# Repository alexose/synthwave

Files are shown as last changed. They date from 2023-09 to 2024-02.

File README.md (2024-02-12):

# Synthwave

An open-source experiment in carbon removal based on the electrochemical pH swing of seawater.


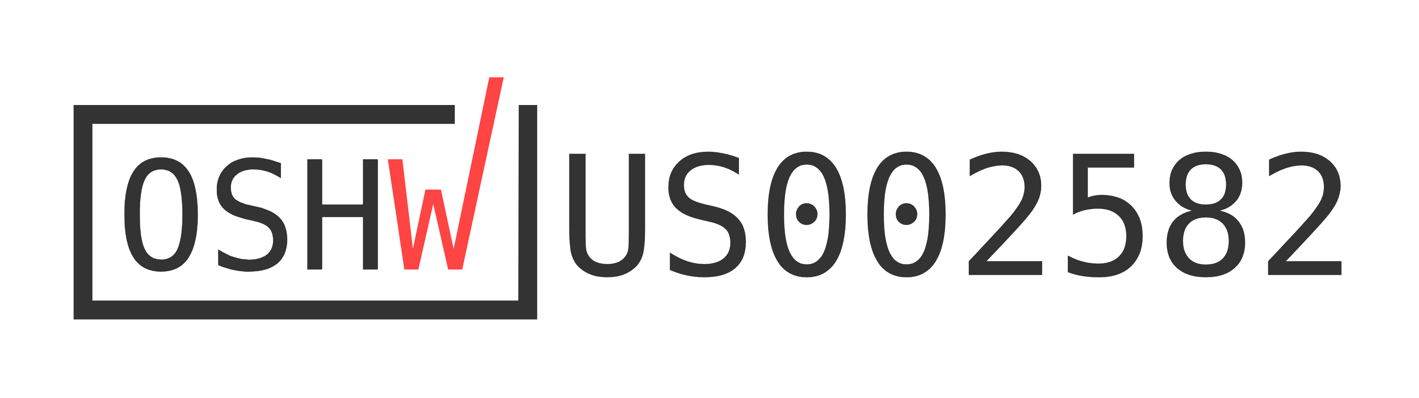
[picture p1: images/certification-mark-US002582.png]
OSHWA-Logo
[](https://certification.oshwa.org/us002582.html)

<p float="left">
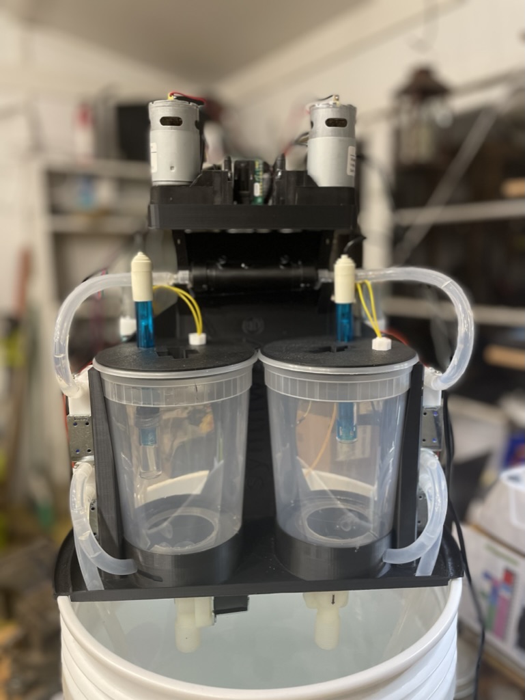
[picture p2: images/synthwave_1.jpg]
  
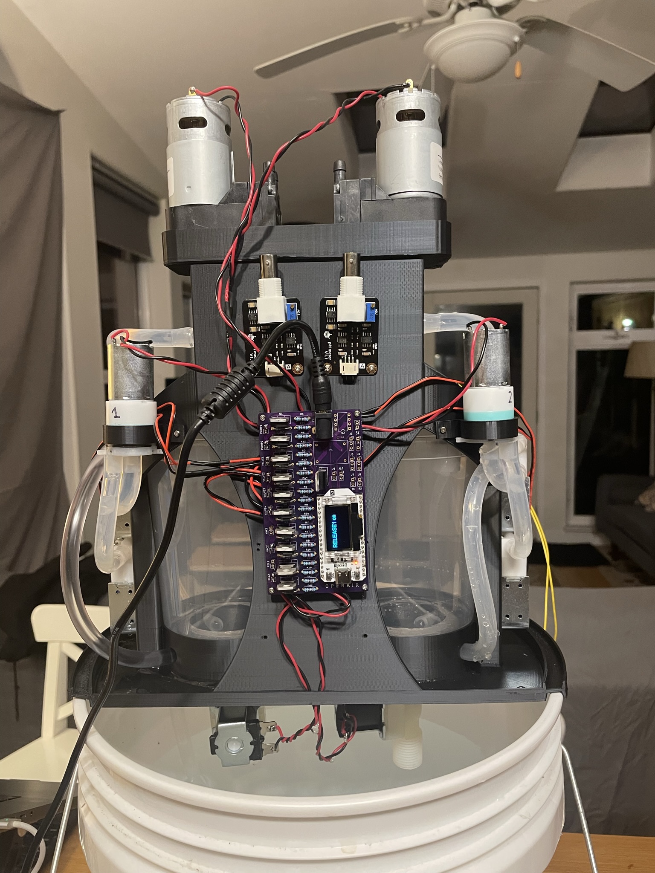
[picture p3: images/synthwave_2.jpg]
  
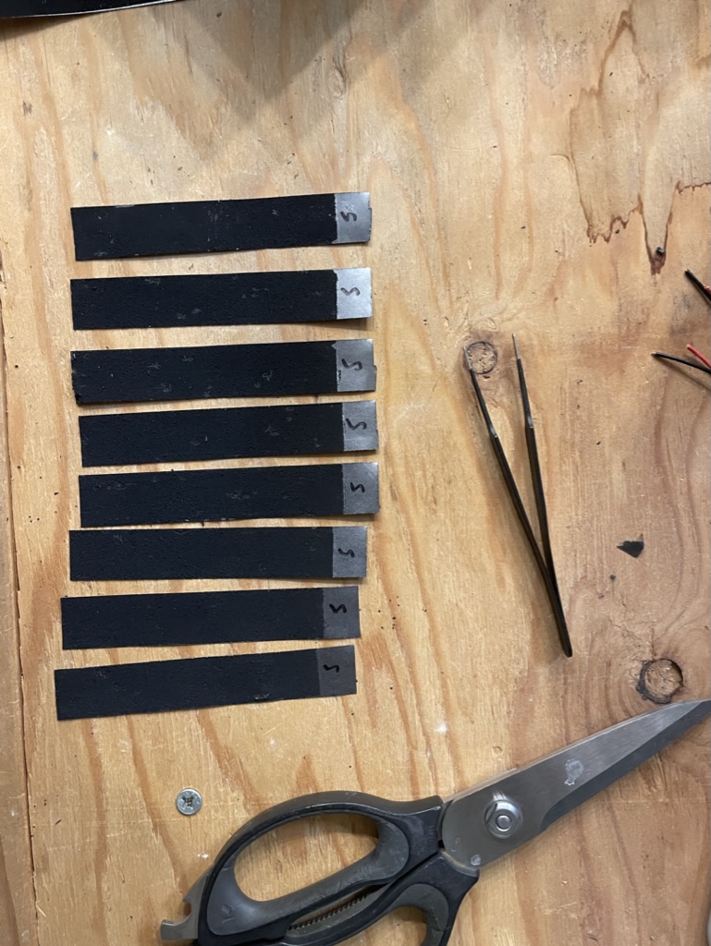
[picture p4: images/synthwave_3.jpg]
  
</p>

Developed by Alex Ose with input from many wonderful collaborators via the
[OpenAir Collective](https://openaircollective.cc/).

-   [OpenAir Forums](https://www.openairforum.org/t/introducing-synthwave/806)
-   [OpenAir Discord](https://openaircollective.cc/join)

## Introduction

Synthwave demonstrates the removal of CO2 from seawater using
[a technique developed by the Alan Hatton lab at MIT](https://pubs.rsc.org/en/content/articlelanding/2023/EE/d2ee03804h)
using a 3D printed shell and common, off-the-shelf components. With a materials list under $300, Synthwave is designed
to be an entry point for anyone looking to learn more about ocean-based carbon capture.

It is designed to be fully hackable, with an emphasis on approachability. Our goal is to bring ocean-based
electrochemical capture to a wider audience!

## Hardware

### Moving parts

The hardware is based around cheap 12V devices (that can easily be sourced from Amazon or eBay) controlled by a common
ESP32 microcontroller. The full list of materials can be found [here](MATERIALS.md).

### 3D printed parts

Each of the above parts are mounted onto a 3D printed frame that can be found in the `/model` directory of this repo.
Because it is designed to sit on top of a standard 5-gallon bucket, printing this frame requires a large-format printer
with a build area of at least 320x320mm.

There are several parts:

-   Base
-   Container cover
-   Back cover (optional)
-   Two pump brackets
-   Two strain relief brackets
-   Two electrode holders

Please refer to the README.md inside of the `/model` directory for pointers on how to print and assemble the device.

### Electrodes

As this is an electrochemistry project, it requires electrodes. While the exact formulation of these are under active
development, I would be happy to send you a working set of electrodes for free. Please get in touch with me directly in
order to arrange this.

Should you choose to develop your own electrodes, please consult
[this thread in the OpenAir forums](https://www.openairforum.org/t/synthwave-electrochemical-co2-capture-from-seawater/781/4)
for more information.

## Software

The software that controls this system is designed to be as readable as possible. It uses Arduino-compatible code to
connect to a local WiFi network and expose a simple API. This API accepts various parameters that allow a client to
toggle each individual pump, solenoid, and/or electrode set.

This allows us to control the system entirely from a web browser, which allows easy fine-tuning of process variables
without the need to continuously re-flash the ESP32 server.

Should you need to re-flash the ESP32, this can be accomplished via the /update endpoint. The software uses the
[ElegantOTA](https://github.com/ayushsharma82/ElegantOTA) library to allow for simple, over-the-air reflashing as to not
require a physical connection to the device.

## System modeling

Our current estimates show that Synthwave removes about of 0.076g of CO2 per run cycle[1]. Assuming a cycle time of five
minutes, an unlimited source of seawater, and non-degrading electrodes, it should be able to remove 22g of CO2 per day.

There are many, many variables that will affect this final number: The quality of the electrodes, the concentration of
CO2 in the seawater, the cycle frequency, and the efficiency of our electrochemical reaction.

Above all else, Synthwave aims to put our assumptions to the test, and help inform our next phase of research.

[1]: The original paper cites 0.0543 mmol of CO2 removed per cycle, with water volumes of about 30mL. Scaling this up to
1L gives us 1.7404 mmol, or 0.0766 grams of CO2.

## Future research

Synthwave is designed to be a simple demonstration of a specific carbon capture technique. In order to achieve
commercial viability, virtually all aspects of this technique will need to be improved.

The main need is to improve the quality of our electrodes. This will likely involve better coating techniques to avoid
degredation and fouling, as well as more accurate measurements, CV charts, etc.

With improved electrodes, the next step would be to improve the throughput of the device to handle much more seawater.
This could be achieved by increasing the size of the system, designing a more efficient cell (ideally a flow cell), or
perhaps building multiple machines to work in parallel with one another.

We hope that by publishing this work under the CERN license, future hackers and collaborators will share their
learnings. It is only by the overwhelming success of carbon capture do we hope to maintain a livable climate. By
investing your time and energy in projects like this one, we may uncover key techniques that make gigaton-scale carbon
capture viable.

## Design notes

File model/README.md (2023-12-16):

# Synthwave 3D Models

The following are a few notes on how to print this design. This is not meant to be a comprehensive tutorial. More of an
FAQ. Please consider checking out the [build log](https://www.openairforum.org/t/synthwave-build-log/904) for additional
guidance.

If you're having trouble with the build process, I encourage you to reach out to me directly in the OpenAir discord.

## Base

This is the main piece of Synthwave, and is responsible for consuming the majority of the filament. It's a big piece:
Around 320x320x235mm, and will require about half a roll of filament (500g) if printed at 10% infill.

If you don't have a big enough printer, you may use the base_no_lid.stl file. This model should print on a
standard-sized printer, but it requires you to purchase a lid for your five-gallon bucket and drill two holes in it.
These holes should line up with the flush valves. Done correctly, the flush valves will hold everything in place.

You'll notice several mounting points. These are designed for M2 screws. I highly recommend a set of assorted
self-tapping M2 screws for this project, as you may need many different lengths. Also, the holes are on the small side,
so you might want to drill them out ever so slightly to allow the screws to bite.

## Container cover

This sits on top of the two 32oz deli containers, and acts as a place to hold a pH probe, a float switch, and a pair of
electrodes.

## Pump brackets

These allow you to screw the two micro pumps to each side of the base.

## Electrode holders

These clips are designed to hold an electrode pair 1cm apart. They're meant to allow for quick electrode swaps, and are
supposed to sit just above the water line.

## Back cover (optional)

This piece is designed to protect the breadboard. It is not really needed unless you want to protect the electronics.

## Strain relief brackets (optional)

Instead of the back cover, you can also use these brackets to help secure all of the different wires in place.

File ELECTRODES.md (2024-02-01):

# Alex's Guide to DIY Carbon Paper Electrodes

## Introduction

Carbon paper electrodes are a good starting point for many electrochemical experiments. While there are many styles,
these ones lend themselves to DIY production.

In these examples, we will be creating two types of electrodes. One made with bismuth powder, and the other with silver
chloride powder. These happen to be the same types needed for [Synthwave](https://github.com/alexose/synthwave).

Note that I'm just a hobbyist, not a professional electrochemist. It is likely that there are better techniques than
this one-- However, this is the one I've found that works best for my particular setup and workflow.

## Materials Needed

I've provided links below, but they're likely to fall victim to [link rot](https://en.wikipedia.org/wiki/Link_rot) over
time. If a link isn't working, just do your best to find a suitable replacement.

I also included amounts, but keep in mind that this will buy you much more than you need for a single set of electrodes.
The intention here is that you'll have enough material to make as many as you want.

-   50g
    [Carbon Black](https://www.msesupplies.com/products/mse-pro-50g-super-p-conductive-carbon-black-for-lithium-ion-battery)
    (Carbon Powder)
-   50g
    [Polyvinylidene Floride](https://www.msesupplies.com/products/mse-pro-100g-polyvinylidene-fluoride-pvdf-binder-for-lithium-battery-research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),
    a binding agent
-   Metal powders, in this example both [bismuth](https://www.rotometals.com/bismuth-powder-99-99-325-mesh-1-pound/) and
    [silver chloride](https://www.ebay.com/itm/395123679024?hash=item5bff34df30:g:QNQAAOSwjy1fVxHt)
-   500mL of
    [NMP](https://www.laballey.com/products/nmp-1-methyl-2-pyrrolidone-lab-grade?utm_source=Klaviyo&utm_medium=flow)
    solvent
-   At least a square foot of .005" thickness
    [Carbon Paper](https://www.amazon.com/MinGraph-Flexible-Graphite-Thickness-Homogeneous/dp/B07K8Y4269) (AKA Graphite
    Paper)
-   A razor scraper. I like [this one](https://www.thingiverse.com/thing:2029655), personally, but anything will work
-   Ink casting guides (see below)
-   A digital scale that works in the thousandth range
-   A plastic spoon
-   Latex gloves

## Ink casting guides

The key to electrode creation is achieving a very thin and very even spread of "ink" onto a the sheet of carbon paper.
The high-end way to do this is with a CNC-assisted spray nozzle. The low-end way is to do something called the "doctor
blade" method, which involves laying down several layers of scotch tape in lines to a desired thickness, then using a
razor blade to smoothly cast the ink between the lines.

I use a modified doctor blade method, where I 3D print stencils rather than using up a whole roll of tape. The
electrodes I'm aiming for are 20 cm² rectangles, cast a depth of 200 μm (0.2mm). The files I use are
[included in the Synthwave repo](https://github.com/alexose/synthwave/blob/main/model/ink_spreader.stl), but are easy to
create on your own using the CAD tool of your choice.

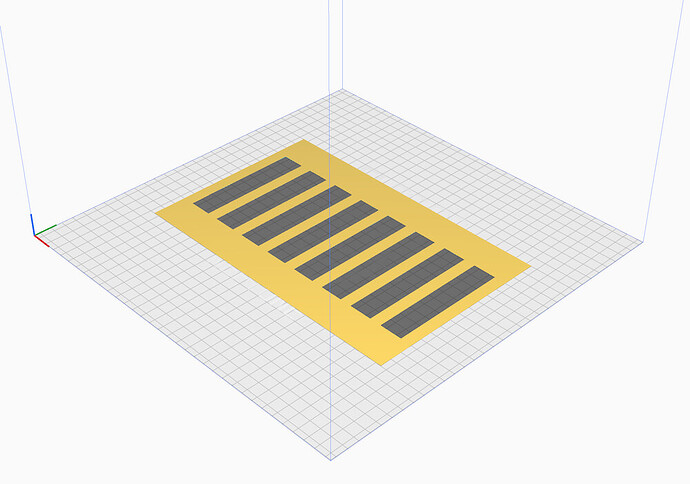
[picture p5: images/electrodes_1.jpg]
image|690x485, 50%


3d printers are excellent when it comes to making accurately-sized things. Do keep in mind that the first layer of any
3d print is mildly "squished", and may not end up _exactly_ the thickness you anticipate. Always good to verify with
calipers.

If you don't have a 3d printer, you may use the scotch tape method.

## Safety Precautions

While these ingredients aren't particularly toxic, please make sure to take proper safety precautions when handling
powders, solvents, and/or razor blades.

Carbon black is especially powdery, and is not very good for your when inhaled. Wear a mask!

This process can also be a little messy, so I like to wear latex gloves.

## Creating The Ink

Begin by weighing your ingredients. The [paper](https://pubs.rsc.org/en/content/articlelanding/2023/ee/d2ee03804h) that
I'm working from only states ratios, which is not particularly useful for knowing how much to make. For your
convenience, I've included exact weights for each ingredient, which will make enough ink to cover about 200 cm² of
surface area (so, 8 electrodes with a little bit of excess).

Tare your mortar and pestle on your scale, then carefully add:

-   0.4g carbon black
-   0.4g PVDF
-   3.2g bismuth powder (or silver chloride, depending on which you're making)
-   10.0g NMP solvent

Use your mortar and pestle to mix thoroughly. You're aiming for a perfectly smooth ink with no lumps.

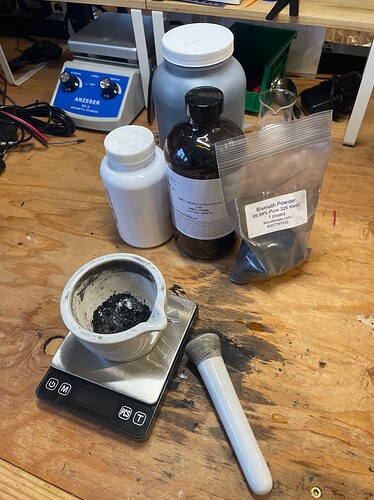
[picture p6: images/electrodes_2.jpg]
image|375x500, 50%
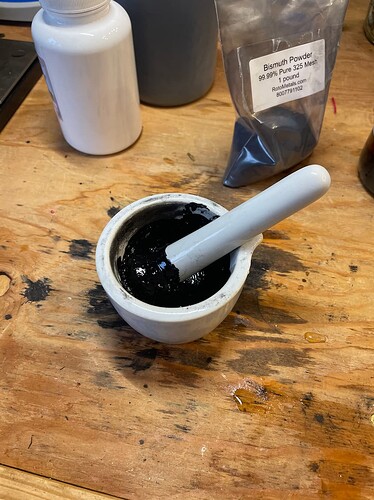
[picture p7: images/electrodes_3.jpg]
image|375x500, 50%
 

When you've achieved this, set up your casting station. My approach here is to tape the 3D printed stencil to both the
carbon paper and the workbench, then drop a spoonful of ink into each lane.

Now use your razor scraper to spread the ink as evenly as you can. Apply even pressure as you drag the razor scraper
across the stencil. You'll notice that the guide is designed to give you enough room to scrape two lanes at once. You
may then remove the stencil and admire your handywork.

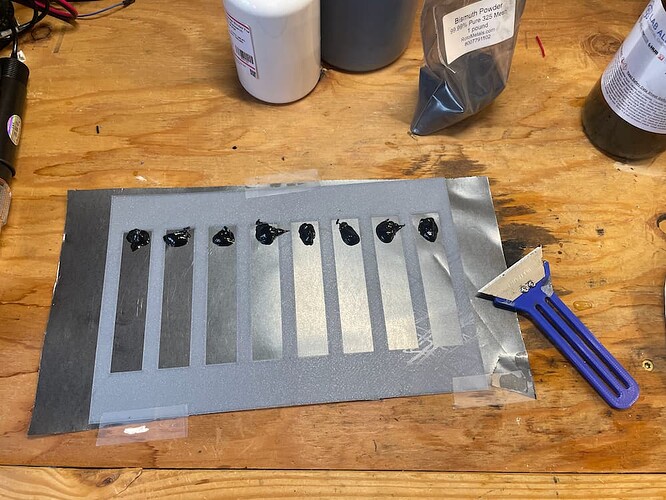
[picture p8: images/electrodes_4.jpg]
image|666x500, 50%
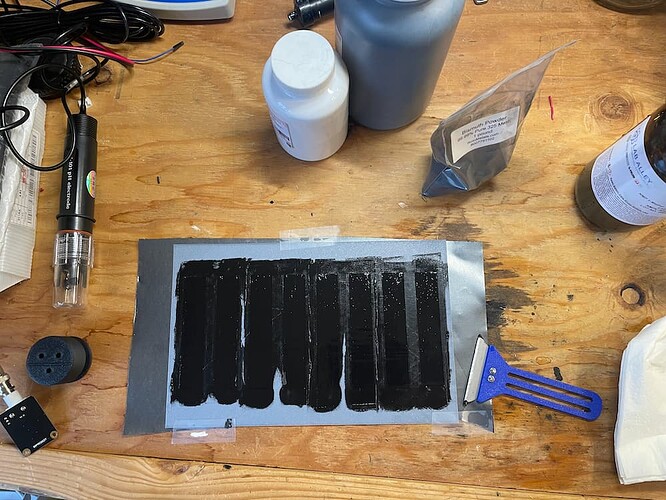
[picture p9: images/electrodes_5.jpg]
image|666x500, 50%
 
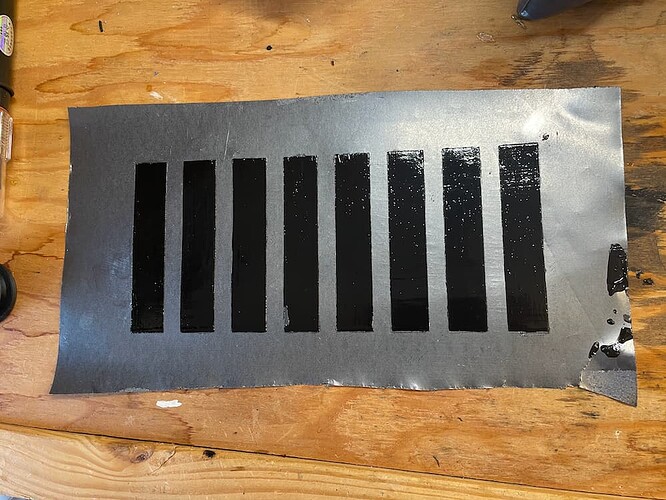
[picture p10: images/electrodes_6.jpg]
image|666x500, 50%


## Cleanup

The bad news is that this ink material is not water-soluable. The good news is that it tends to gel together and come
off in long sheets. The best way I've found to clean my implements is to splash them with very cold water, dry with a
paper towel, and repeat.

## Drying the electrodes

If you're in a hurry, you can dry them in an 180F oven for 3 hours (I personally use the back of a cookie sheet).
Otherwise, you can leave them at room temperature for 24 hours.

Once they're dry, carefully cut them into their desired shapes using scissors or a paper cutter.

Congratulations! You have now completed your first set of electrodes.

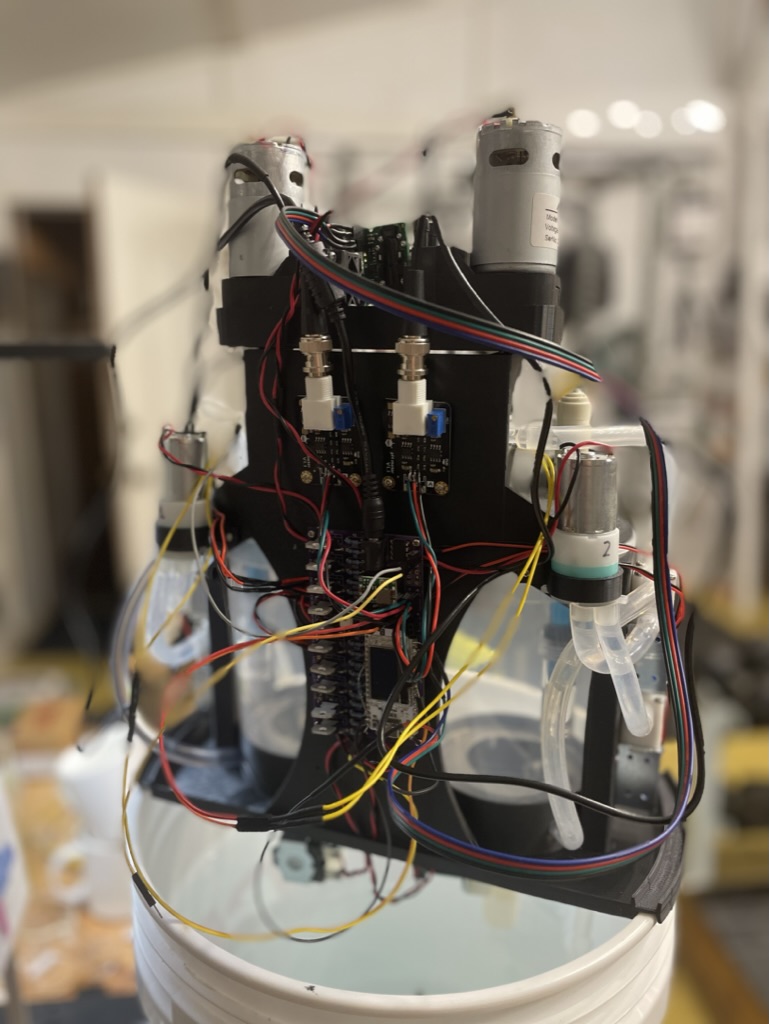
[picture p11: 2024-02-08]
images/synthwave_4.jpg

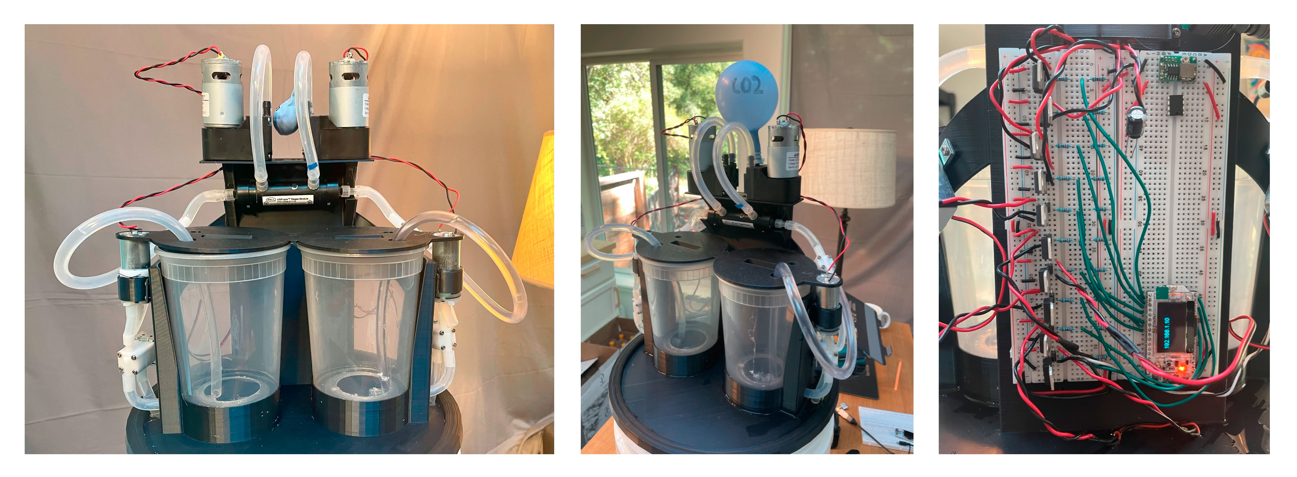
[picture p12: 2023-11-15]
images/synthwave.jpg

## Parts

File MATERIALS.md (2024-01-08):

# List of Materials

This should be everything you need to build a Synthwave. Note that these parts (and associated links) may change over
time. If in doubt, make sure to cross-reference with photos of existing builds.

## Custom Parts

Synthwave requires a few parts that can't be easily ordered off the internet. First is a 3d printed [shell](/model), as
well as several other 3d printed bits. I recommend using a good quality, large format 3d printer if possible. If you
only have access to a small printer, you may need to get creative.

You'll also need the official [Synthwave PCB](/pcb). This custom-designed board allows a simple ESP32 to control ten
different 12 volt devices at once, as well as breaking out various inputs and outputs needed for managing the
electrochemical process.

If you've never ordered a custom PCB, I highly recommend [OSHPark](https://oshpark.com/). You can order three boards for
about $40 (having extra is never a bad idea).

The board is designed to be populated by hand: Everything is through-hole, and nothing is surface mounted. If you're
experienced with soldering, this should take you about an hour or so. If you're not experienced with soldering, well,
this is a good opportunity to learn!

## Pumps

-   2 [DC 12V Water Flow Self Priming Diaphragm Micro Water Pumps](https://www.amazon.com/gp/product/B09NQZHBQ2) $25.18
    ($12.59 ea)
-   2
    [DC 12V Mini Vacuum Pump](https://www.amazon.com/gp/product/B071GL3XXQ/ref=ppx_yo_dt_b_search_asin_title?ie=UTF8&psc=1)
    $51.98 ($25.99 ea)

## Solenoids

-   2 [1/2 inch NPT Thread 12V DC GRAVITY-FEED Plastic Nylon Solenoid Valve](https://www.ebay.com/itm/290763981675)
    $31.98 ($15.99 ea). It is very important that you use GRAVITY FEED valves. Don't sub these out for "regular" valves,
    which require a certain amount of pressure to open.
-   4 [12V Two-Position Three-Way Electric Solenoid Valve](https://www.aliexpress.us/item/3256804915255792.html) $20
    (about $5 each) (Note there are a wide variety of these three-way solenoids. I highly recommend the ones with the
    barbed fittings.)

## Membrane Contactor

-   1 [UDM-21110 Ultifuzor Degas Module](https://www.ebay.com/itm/115469063200) ~$180 (I bought used for $75)
-   4 [Luer lock to 1/4 barb fitting adapter](https://www.amazon.com/gp/product/B0BB649WM2/) $7.99 (10 pack)

## Sensors + Electronics

-   1 [SCD30 CO2 sensor](https://www.amazon.com/extralife-Quality-Sensors-Module-Measurements/dp/B0BBGSQTYJ) $30.40
-   2 [Gravity Arduino-compatible pH sensors](https://www.dfrobot.com/product-1782.html) $79.00 ($39.50 ea)
-   1
    [Heltec Wifi Kit 32 V3 Development Board with OLED](https://www.amazon.com/HiLetgo-Display-Bluetooth-Internet-Development/dp/B07DKD79Y9)
    $17.39
-   1 [15V DC 3A Power Supply](https://www.amazon.com/Adapter-Switching-Converter-100V-240V-Positive/dp/B08CZD4HWG)
    $12.99
-   1 [Adafruit 4489 L9110H H-Bridge](https://www.amazon.com/gp/product/B085KYNY3H/) $5.18
-   1 [L7805CV Voltage Regulator](https://www.amazon.com/dp/B0C5M51R2Z) $5.99 (12 pack) 1
    [3 pin DC Power Connector, DC005 5.5x2.1mm](https://www.amazon.com/dp/B081DYQSC9) $5.99 (20 pack)
-   10 [TIP120 NPN 5A 60V Transistors](https://www.amazon.com/gp/product/B08BFYYK7D/ref=ppx_yo_dt_b_search_asin_title)
    $8.99 (20 pack)
-   2
    [LM2596S Adjustable Buck Converter](https://www.amazon.com/DiGiYes-Converter-Efficiency-Regulator-Adjustable/dp/B0BPSFVDY4)
    $8.69 (5 pack)

## PCB

## Electrode Materials

## Misc.

-   20 [2.2kohm 1/4 watt resistors](https://www.amazon.com/dp/B08QRPRVMJ) (used as hardware pulldowns) $5.49 (100 pack)
-   10 [30v 1A diodes](https://www.amazon.com/ALLECIN-1N5818-Schottky-Rectifier-Switching/dp/B0CKSHS9CM) (used as
    flyback diodes) $6.49 (150 pack)
-   10 feet [1/4" ID 3/8" OD silicone tubing](https://www.amazon.com/dp/B07W918CBP) ~ $5
-   Solid core wire for electronics
-   Shrink tubing
-   Wire strippers, needlenose pliers, soldering iron, etc.

You should expect everything to cost around **$400** total. Of course, it is quite a bit cheaper to source all the parts
from China if you don't mind the wait.

The most expensive individual part is the membrane contactor. It would be interesting to come up with an alternative for
this part, but I'm not sure what this would be. The pH sensors are optional, but very useful to monitor system
performance.

With careful attention to price, it would be possible to build this device for around $200.

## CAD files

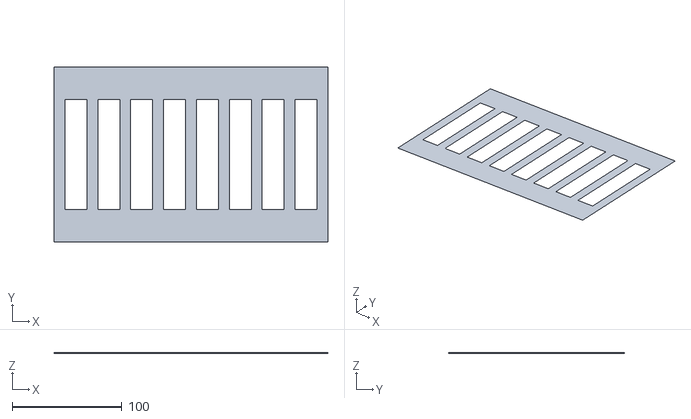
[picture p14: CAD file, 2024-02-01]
model/ink_spreader.stl
250.0 x 160.0 x 0.24

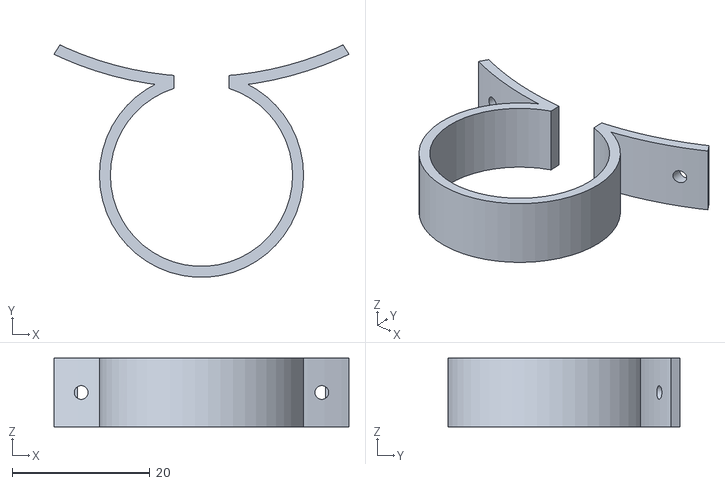
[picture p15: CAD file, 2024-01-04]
model/pump_bracket.stl
42.9 x 33.8 x 10.0

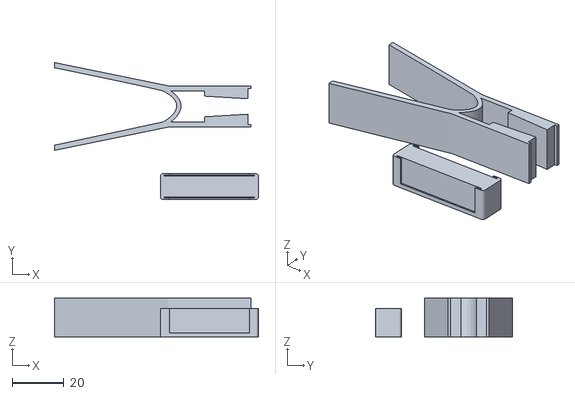
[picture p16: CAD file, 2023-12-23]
model/electrode_holder.stl
79.0 x 53.0 x 15.0

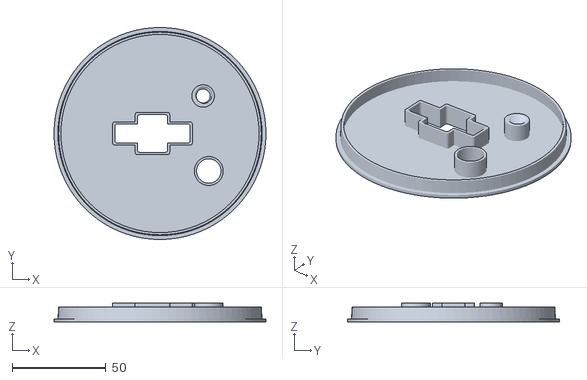
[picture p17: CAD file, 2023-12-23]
model/container_cover.stl
113.0 x 113.0 x 10.0

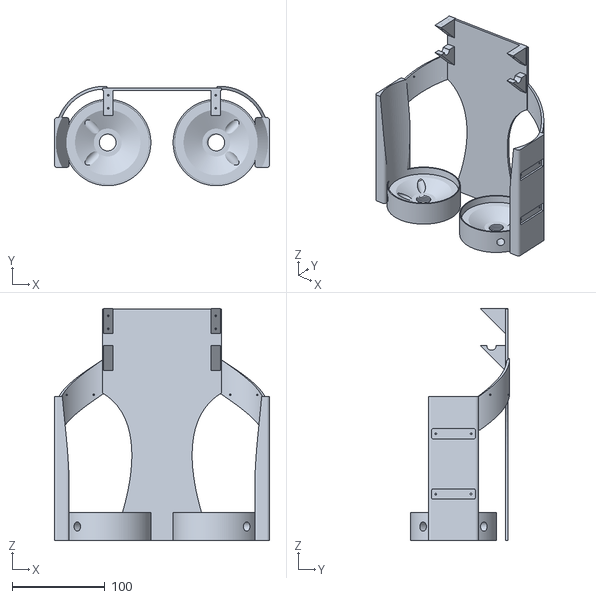
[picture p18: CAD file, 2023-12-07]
model/base_no_lid.stl
232.0 x 107.1 x 250.0

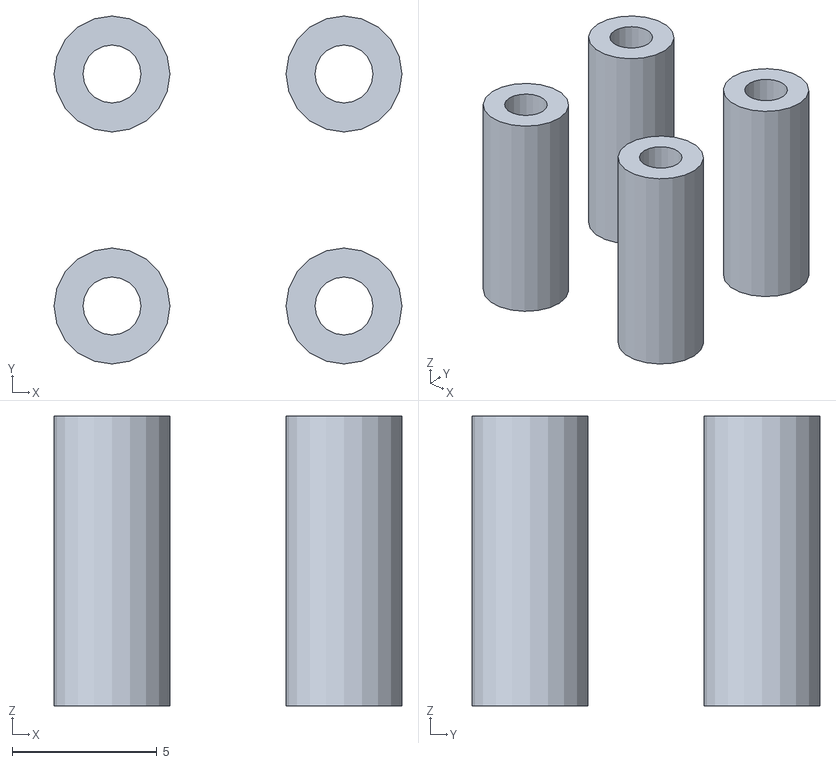
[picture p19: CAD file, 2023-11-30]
model/standoffs.stl
12.0 x 12.0 x 10.0

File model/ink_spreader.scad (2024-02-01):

// Modified Doctor Blade sheet
w = 250;
h = 160;
d = 0.24; // 240um

electrode_width = 20;
electrode_height = 100;

difference() {
    cube([w, h, d], true);
    
    // Loop to create multiple instances of the second cube
    for (x = [0 : 20+10 : 250]) {
        translate([x - w/2 + 20, 0, 0])
            cube([electrode_width, electrode_height, d+0.1], true);
    }
}

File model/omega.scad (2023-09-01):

h = 15; // height
w = 45; // flange width
fd = 6; // flange depth
d = 1.6; // thickness
r1 = 27 / 2; // outer radius
r2 = 1.8; // screw hole head radius
r3 = 0.8; // screw hole radius
d2 = 4; // screw hole head depth
o = 3.5; // screw hole offset (from outer edges)

b = 2; //vertical bump

$fn = 60;


translate([0, 0, h/2]) rotate([0, 90, 0]) difference() {
    union() {
        hull() standoffs(1, d, h, w);
        translate([0, 0, b]) rotate([90, 0, 90]) cylinder(h, r1+d, r1+d, center=true);
    }
    union() {
        translate([0, 0, b]) rotate([90, 0, 90]) cylinder(h, r1, r1, center=true);  
        translate([0, 0, -h]) cube([h, r1*2, h*2 + h/2], center=true);
        translate([0, w/2 - o, -d2]) cylinder(d + d2, r2, r2);
        translate([0, -w/2 + o, -d2]) cylinder(d + d2, r2, r2);
        translate([0, w/2 - o, -fd]) cylinder(fd + d, r3, r3);
        translate([0, -w/2 + o, -fd]) cylinder(fd + d, r3, r3);
    }
}


module standoffs(r, depth, height, width) {
    $fn = 20;
    d = depth + fd;
    x = height / 2 - r;
    y = width / 2 - r;
    
    translate([0,0,-fd]) union() { 
        translate([x, y]) cylinder(d, r, r);
        translate([x, -y]) cylinder(d, r, r);
        translate([-x, y]) cylinder(d, r, r);
        translate([-x, -y]) cylinder(d, r, r);
    }
}

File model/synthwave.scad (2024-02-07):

use <threads.scad>

base_radius = 283 / 2; // inner diameter of 5 gallon bucket in mm

container_bottom_radius = 89 / 2;
container_top_radius = 112 / 2;
container_height = 135.3;

pump_mount_depth = 8;
pump_mount_height = container_height + 20;

rear_wall_height = 245;
rear_wall_width = 128;
rear_wall_thickness = 3;

electrode_holder_width = 20;
electrode_holder_height = 12;
electrode_holder_depth = 5;
electrode_holder_radius = 1;

distance_between_containers = 14;

default_screw_radius = 1;

$fn = 50;

render_base = 1;
render_base_no_lid = 0;
render_electrode_holder = 0;
render_pump_bracket = 0;
render_container_cover = 0;
render_back_cover = 0;
render_standoffs = 0;

if (render_base) base();
if (render_base_no_lid) base(false);
if (render_electrode_holder) {
    translate([0, -20]) electrode_holder(); 
    clip();
}
if (render_pump_bracket) pump_bracket();
if (render_container_cover) container_cover();
if (render_back_cover) back_cover();
if (render_standoffs) pcb_standoffs();

module base(include_lid=true) {
    border_width = 10;
    dr = container_bottom_radius;
    bw = border_width;
    
    d = dr + bw * 2;
    r = 20;
        
    dist = dr + distance_between_containers;
    
    pw = 108;
    rw = 56;
    
    y = -3; // nudge forward
    
    // translate([dist, 0]) container();
    // translate([-dist, 0]) container();
    
    difference() {
        union() {
            if (include_lid) {
                lid();
            }
            translate([dist, y]) cylinder(30, r=dr+2, $fn = 140);
            translate([-dist, y]) cylinder(30, r=dr+2, $fn = 140);
            translate([pw, y]) mirror([0, 1, 0]) rotate([0, 0, 180]) pump_mount();
            translate([-pw, y]) pump_mount();
            translate([0, rw]) rear_wall();
            translate([pw + 4, 54.5, 107]) band(35);
            translate([-pw - 4, 54.5, 107]) mirror([1,0,0]) band(35);
        }
        
        a = 45;
        translate([dist, y, -5]) mirror([1, 0]) rotate([180, 180])  solenoid_funnel();
        translate([-dist, y, -5]) rotate([180, 180]) solenoid_funnel();
        translate([0, rw-2, 105]) rotate([90, 270, 0]) linear_extrude(1.2) text("synthwave", size=20, halign="center", valign="center", spacing=1.3);
    }

    module rear_wall() {
        h = rear_wall_height;
        o = rear_wall_thickness;
        w = rear_wall_width / 2;
        
        r = 1;
        w2 = 120;
        h2 = 60;
        
        difference() {
            rotate([90, 0]) rear_wall_polygon();
            translate([0, -1, 115]) rotate([-90, 0]) pcb_screw_holes();
            translate([-17, -1, 175]) rotate([-90, 0]) ph_meter_screw_holes();
            translate([0, -1, 55]) rotate([-90, 0]) ph_meter_screw_holes();
            translate([17, -1, 175]) rotate([-90, 0]) ph_meter_screw_holes();  
        }
        
        translate([0, 0, 175]) shelf();
        
        module rear_wall_cutouts() {
            r = 120;
            c = 35;
            h = 30;
            b = 80;
            $fn = 100;
            
            translate([r + c, 10, b]) rotate([90, 0]) cylinder(h, r=r);
            translate([-r - c, 10, b]) rotate([90, 0]) cylinder(h, r=r);
        }
        
        module rear_wall_holes() {
            r = 12/2;
            c = 48.3/2;
            h = 30;
            b = 205;
            $fn = 80;
            
            translate([r + c, 10, b]) rotate([90, 0]) cylinder(h, r=r);
            translate([-r - c, 10, b]) rotate([90, 0]) cylinder(h, r=r);
        }
    }
}

        
module rear_wall_polygon(height=1, offset=0, def=1) {
    h = rear_wall_height;
    w = rear_wall_width;
    t = rear_wall_thickness;
    
    hf = h / 32;
    wf = w / 24;
    
    // 24x32
    scale([1, 1, t]) 
    translate([-w/2, 0])
    linear_extrude(height)
    offset(r=offset)
    scale([wf, hf])
    if (def == 1){
        rear_wall_polygon_def();
    } else {
        rear_wall_polygon_def2();
    }
}

module rear_wall_polygon_def() {
    polygon([[2,0/*1:0,0,0,0*/] ,[3.07,0] ,[4.08,0] ,[5.13,0] ,[6.32,0] ,[7.36,0] ,[8.47,0] ,[9.62,0] ,[10.8,0] ,[12,0] ,[13.2,0] ,[14.38,0] ,[15.53,0] ,[16.64,0] ,[17.68,0] ,[18.88,0] ,[19.92,0] ,[20.93,0] ,[21.95,0],[22,0/*1:0,0,0,0*/] ,[21.5,0.87] ,[20.97,1.87] ,[20.53,2.77] ,[20.07,3.81] ,[19.6,4.96] ,[19.25,5.95] ,[18.92,6.99] ,[18.63,8.07] ,[18.39,9.18] ,[18.21,10.31] ,[18.11,11.45] ,[18.1,12.58] ,[18.19,13.71] ,[18.39,14.81] ,[18.72,15.87] ,[19.18,16.9] ,[19.8,17.87] ,[20.58,18.77] ,[21.53,19.6] ,[22.36,20.17] ,[23.31,20.69],[24,21/*1:-12,-5,0,5*/] ,[24,22.09] ,[24,23.16] ,[24,24.19],[24,25/*1:0,0,0,0*/] ,[22.9,25.16] ,[21.78,25.3] ,[20.71,25.42] ,[19.68,25.52] ,[18.54,25.61] ,[17.29,25.7] ,[16.23,25.76] ,[15.11,25.82] ,[13.93,25.86] ,[12.71,25.88] ,[11.45,25.89] ,[10.15,25.88] ,[8.81,25.84] ,[7.79,25.8] ,[6.76,25.75] ,[5.71,25.68] ,[4.65,25.59] ,[3.59,25.49] ,[2.52,25.36] ,[1.44,25.22] ,[0.36,25.06],[0,25/*1:12,2,0,-2*/] ,[0,23.99] ,[0,22.92] ,[0,21.82],[0,21/*1:0,5,12,-5*/] ,[1.02,20.52] ,[1.93,19.99] ,[2.97,19.2] ,[3.83,18.33] ,[4.53,17.39] ,[5.07,16.39] ,[5.46,15.34] ,[5.72,14.26] ,[5.87,13.15] ,[5.91,12.02] ,[5.85,10.88] ,[5.71,9.75] ,[5.5,8.63] ,[5.23,7.53] ,[4.92,6.47] ,[4.58,5.45] ,[4.21,4.49] ,[3.74,3.38] ,[3.29,2.39] ,[2.79,1.4] ,[2.27,0.45]]);
}

module rear_wall_polygon_def2() {
    polygon([[3,1/*1:0,0,0,0*/] ,[4.09,1] ,[5.23,1] ,[6.44,1] ,[7.59,1] ,[8.82,1] ,[9.86,1] ,[10.92,1] ,[12,1] ,[13.08,1] ,[14.14,1] ,[15.18,1] ,[16.41,1] ,[17.56,1] ,[18.58,1] ,[19.62,1] ,[20.67,1],[21,1/*1:0,0,0,0*/] ,[20.49,1.93] ,[20.01,2.91] ,[19.54,3.98] ,[19.14,5] ,[18.75,6.13] ,[18.46,7.09] ,[18.21,8.09] ,[18,9.13] ,[17.85,10.19] ,[17.77,11.26] ,[17.77,12.34] ,[17.86,13.41] ,[18.06,14.48] ,[18.37,15.51] ,[18.81,16.51] ,[19.39,17.47] ,[20.11,18.38] ,[21,19.22] ,[22.06,20] ,[22.98,20.52],[24,21/*1:-12,-5,0,5*/] ,[24,22.07] ,[24,23.07] ,[24,24.1],[24,24/*1:0,0,0,0*/] ,[22.9,24.16] ,[21.78,24.3] ,[20.71,24.42] ,[19.68,24.52] ,[18.54,24.61] ,[17.29,24.7] ,[16.23,24.76] ,[15.11,24.82] ,[13.93,24.86] ,[12.71,24.88] ,[11.45,24.89] ,[10.15,24.88] ,[8.81,24.84] ,[7.79,24.8] ,[6.76,24.75] ,[5.71,24.68] ,[4.65,24.59] ,[3.59,24.49] ,[2.52,24.36] ,[1.44,24.22] ,[0.36,24.06],[0,24/*1:12,2,0,-2*/] ,[0,22.98] ,[0,21.92],[0,21/*1:0,5,12,-5*/] ,[1.02,20.52] ,[1.94,20] ,[3,19.22] ,[3.89,18.38] ,[4.61,17.47] ,[5.19,16.51] ,[5.63,15.51] ,[5.94,14.48] ,[6.14,13.41] ,[6.23,12.34] ,[6.23,11.26] ,[6.15,10.19] ,[6,9.13] ,[5.79,8.09] ,[5.54,7.09] ,[5.25,6.13] ,[4.86,5] ,[4.46,3.98] ,[3.99,2.91] ,[3.51,1.93] ,[3.02,1.04]]);
}


module lid() {
    br = base_radius; 
    h = 1;
    r = 8;
    d = 450;
    y = 10; // nudge forward
    
    translate([0, y]) difference() { 
        union() {
            difference() {
                cylinder(h, r=br);
                translate([115, -50, -20]) cylinder(100, r=5);
                translate([-115, -50, -20]) cylinder(100, r=5);
                translate([0, 47.5, -20]) cylinder(100, r=3.5);
            }
            
            $fn = 160;
            rotate_extrude() translate([br, 0]) lid_cutout_shape();
            
            // Anti flex bars
            w = br * 2 - 50;
            h = 1.6;
            d = 10;
            b = 83;
            n = 0;
            
            translate([0, b - n, d/2]) cube([w,h,d], center=true);
            translate([0, -b - n, d/2]) cube([w,h,d], center=true);
        }
        translate([0, -d/2]) cube([br*2, br*2, 40], center=true);
        translate([0, d/2]) cube([br*2, br*2, 40], center=true);
    }
}

module shelf(makeSquare=false, extraHoles=false) {
    difference() {
        translate([0, 0, -6]) shelf_brackets();
        d1 = 220;
        d2 = 220;
        d3 = 150;
        d4 = 100;
        z = 20;
        
        // translate([-d1/2, -17, z]) rotate([0, 90]) cylinder(d1, r=5);
        translate([-d2/2, -17, z]) rotate([0, 90]) cylinder(d2, r=6.5);
        translate([-d4/2, -17, z]) rotate([0, 90]) cylinder(d4, r=14);
    }
}


module shelf_brackets() {
    d = 67;

    translate([d, -2]) rotate([0, 0, 270]) vac_shelf_bracket();
    mirror([1, 0, 0]) translate([d, -2]) rotate([0, 0, 270]) valve_shelf_bracket();
    // mirror([1, 0, 0]) translate([d, -2]) rotate([0, 0, 270]) vac_shelf_bracket();
}

module vac_shelf_bracket() {
    t = 2;
    h = 40;
    w = 67;
    d = 10;
    o = -5;
    v = 5;
    
    difference() {
        hull() {
            translate([o - 0.7, -d/2 + 3, h]) scale(1.06)  vac_footprint(v);
            sphere(t);
        }
        translate([o + 0.6, -d/2 + 3, h+1]) vac_footprint(v);
    }
}

module valve_shelf_bracket() {
    t = 2;
    h = 40;
    w = 67;
    d = 10;
    o = -5;
    
    difference() {
        hull() {
            translate([o - 0.7, -d/2 + 3, h]) scale(1.06) valve_footprint(1);
            sphere(t);
        }
        translate([o + 15, -d/2 + 3, h]) rotate([0, 0, 0]) three_way_valve_mount();
    }
}
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

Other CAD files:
model/threads.scad

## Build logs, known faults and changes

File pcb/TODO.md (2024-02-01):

A few known issues that need attention:

-   Pin 26 conflicts with the ESP32's wifi capability. Recommend switching this to pin 20
-   Pin 39 does not have a hardware pullup, recommend adding one
-   Fix issue with ground nets
-   Consider freeing up pin 41 and pin 42 for I2C
-   Consider 20-pin ribbon cable for devices
-   Consider 3-pin ribbon cables for pH meters
-   Consider magnetic connectors for electrodes and/or float sensors

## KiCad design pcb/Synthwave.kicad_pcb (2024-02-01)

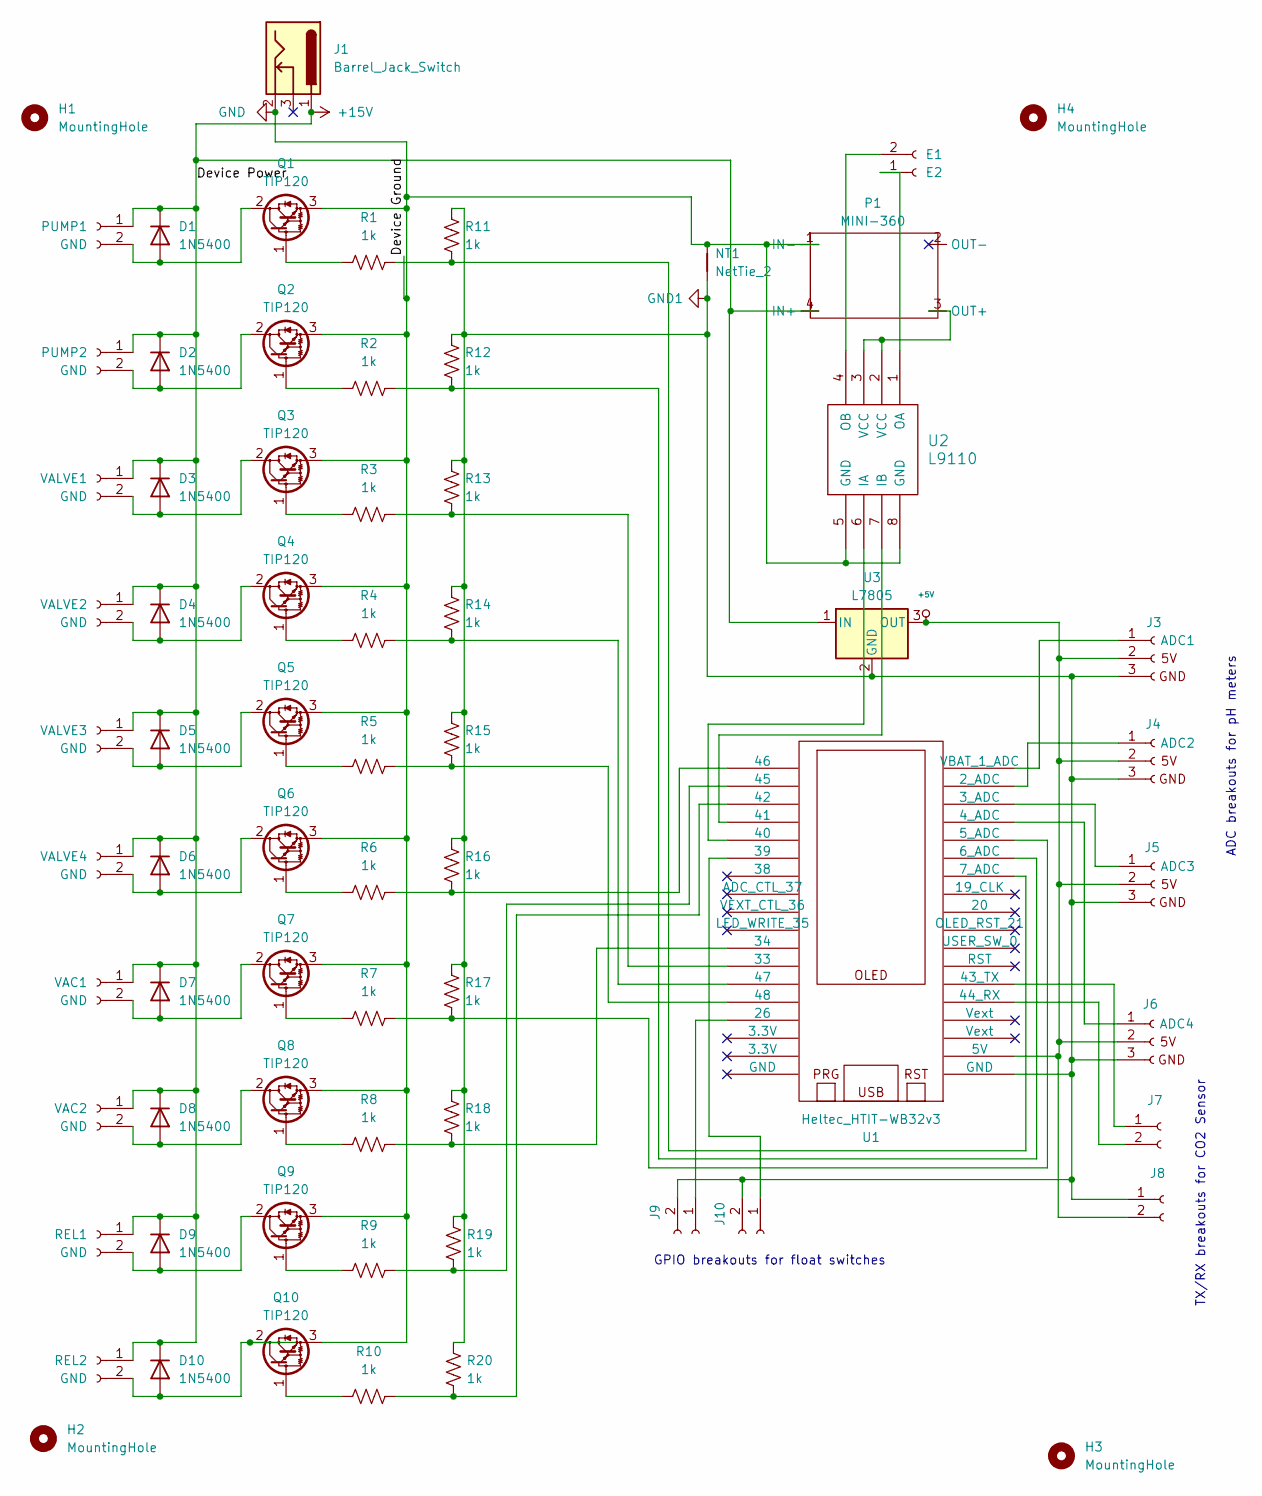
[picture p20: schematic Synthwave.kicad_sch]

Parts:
D1, D2, D3, D4, D5, D6, D7, D8, D9, D10: 1N5400; D_DO-34_SOD68_P10.16mm_Horizontal
E2: E1; PinSocket_1x02_P2.54mm_Vertical
H1, H2, H3, H4: MountingHole; MountingHole_2.2mm_M2
J1: Barrel_Jack_Switch; BarrelJack_Horizontal
J3: ADC1; PinSocket_1x03_P2.54mm_Vertical
J4: ADC2; PinSocket_1x03_P2.54mm_Vertical
J5: ADC3; PinSocket_1x03_P2.54mm_Vertical
J6: ADC4; PinSocket_1x03_P2.54mm_Vertical
J7: TX; PinSocket_1x02_P2.54mm_Vertical
J8: RX; PinSocket_1x02_P2.54mm_Vertical
J9: GPIO26; PinSocket_1x02_P2.54mm_Vertical
J10: GPIO39; PinSocket_1x02_P2.54mm_Vertical
NT1: NetTie_2; NetTie-2_THT_Pad1.0mm
P1: MINI-360
PUMP1, PUMP2: GND; PinSocket_1x02_P2.54mm_Vertical
Q1, Q2, Q3, Q4, Q5, Q6, Q7, Q8, Q9, Q10: TIP120; TO-220-3_Vertical
R1, R2, R3, R4, R5, R6, R7, R8, R9, R10, R11, R12, R13, R14, R15, R16, R17, R18, R19, R20: 1k; R_Axial_DIN0207_L6.3mm_D2.5mm_P7.62mm_Horizontal
REL1, REL2: GND; PinSocket_1x02_P2.54mm_Vertical
U1: Heltec_HTIT-WB32v3; Heltec_HTIT-WB32
U2: L9110; DIP-8_W7.62mm
U3: L7805; TO-220-3_Vertical
VAC1, VAC2: GND; PinSocket_1x02_P2.54mm_Vertical
VALVE1, VALVE2, VALVE3, VALVE4: GND; PinSocket_1x02_P2.54mm_Vertical

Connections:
+5V: J3.2, J4.2, J5.2, J6.2, J8.2, U1.9 (5V), U3.3 (OUT)
+15V: D1.1 (K), D2.1 (K), D3.1 (K), D4.1 (K), D5.1 (K), D6.1 (K), D7.1 (K), D8.1 (K), D9.1 (K), D10.1 (K), J1.1, P1.4 (IN+), PUMP1.1, PUMP2.1, REL1.1, REL2.1, U3.1 (IN), VAC1.1, VAC2.1, VALVE1.1, VALVE2.1, VALVE3.1, VALVE4.1
GND: J1.2, NT1.2, P1.1 (IN-), Q1.3 (E), Q2.3 (E), Q3.3 (E), Q4.3 (E), Q5.3 (E), Q6.3 (E), Q7.3 (E), Q8.3 (E), Q9.3 (E), Q10.3 (E), U2.5 (GND), U2.8 (GND)
GND1: J3.3 (PIN), J4.3 (PIN), J5.3 (PIN), J6.3 (PIN), J8.1, J9.2, J10.2, NT1.1, R11.2, R12.2, R13.2, R14.2, R15.2, R16.2, R17.2, R18.2, R19.2, R20.2, U1.8 (GND), U3.2 (GND)
unnamed: D1.2 (A), PUMP1.2, Q1.2 (C)
unnamed: D2.2 (A), PUMP2.2, Q2.2 (C)
unnamed: D3.2 (A), Q3.2 (C), VALVE1.2
unnamed: D4.2 (A), Q4.2 (C), VALVE2.2
unnamed: D5.2 (A), Q5.2 (C), VALVE3.2
unnamed: D6.2 (A), Q6.2 (C), VALVE4.2
unnamed: D7.2 (A), Q7.2 (C), VAC1.2
unnamed: D8.2 (A), Q8.2 (C), VAC2.2
unnamed: D9.2 (A), Q9.2 (C), REL1.2
unnamed: D10.2 (A), Q10.2 (C), REL2.2
unnamed: E2.1, U2.1 (OA)
unnamed: E2.2, U2.4 (OB)
unnamed: J3.1, U1.36 (VBAT_1_ADC)
unnamed: J4.1, U1.37 (2_ADC)
unnamed: J5.1, U1.38 (3_ADC)
unnamed: J6.1, U1.39 (4_ADC)
unnamed: J7.1, U1.12 (43_TX)
unnamed: J7.2, U1.13 (44_RX)
unnamed: J9.1, U1.10 (26)
unnamed: J10.1, U1.5 (39)
unnamed: P1.3 (OUT+), U2.2 (VCC), U2.3 (VCC)
unnamed: Q1.1 (B), R1.1
unnamed: Q2.1 (B), R2.1
unnamed: Q3.1 (B), R3.1
unnamed: Q4.1 (B), R4.1
unnamed: Q5.1 (B), R5.1
unnamed: Q6.1 (B), R6.1
unnamed: Q7.1 (B), R7.1
unnamed: Q8.1 (B), R8.1
unnamed: Q9.1 (B), R9.1
unnamed: Q10.1 (B), R10.1
unnamed: R7.2, R17.1, U1.34 (5_ADC)
unnamed: R2.2, R12.1, U1.35 (6_ADC)
unnamed: R1.2, R11.1, U1.32 (7_ADC)
unnamed: R3.2, R13.1, U1.15 (33)
unnamed: R8.2, R18.1, U1.2 (34)
unnamed: U1.18 (40), U2.6 (IA)
unnamed: U1.23 (41), U2.7 (IB)
unnamed: R10.2, R20.1, U1.19 (42)
unnamed: R9.2, R19.1, U1.22 (45)
unnamed: R6.2, R16.1, U1.21 (46)
unnamed: R4.2, R14.1, U1.3 (47)
unnamed: R5.2, R15.1, U1.1 (48)

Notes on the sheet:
ADC breakouts for pH meters
TX/RX breakouts for CO2 Sensor
GPIO breakouts for float switches

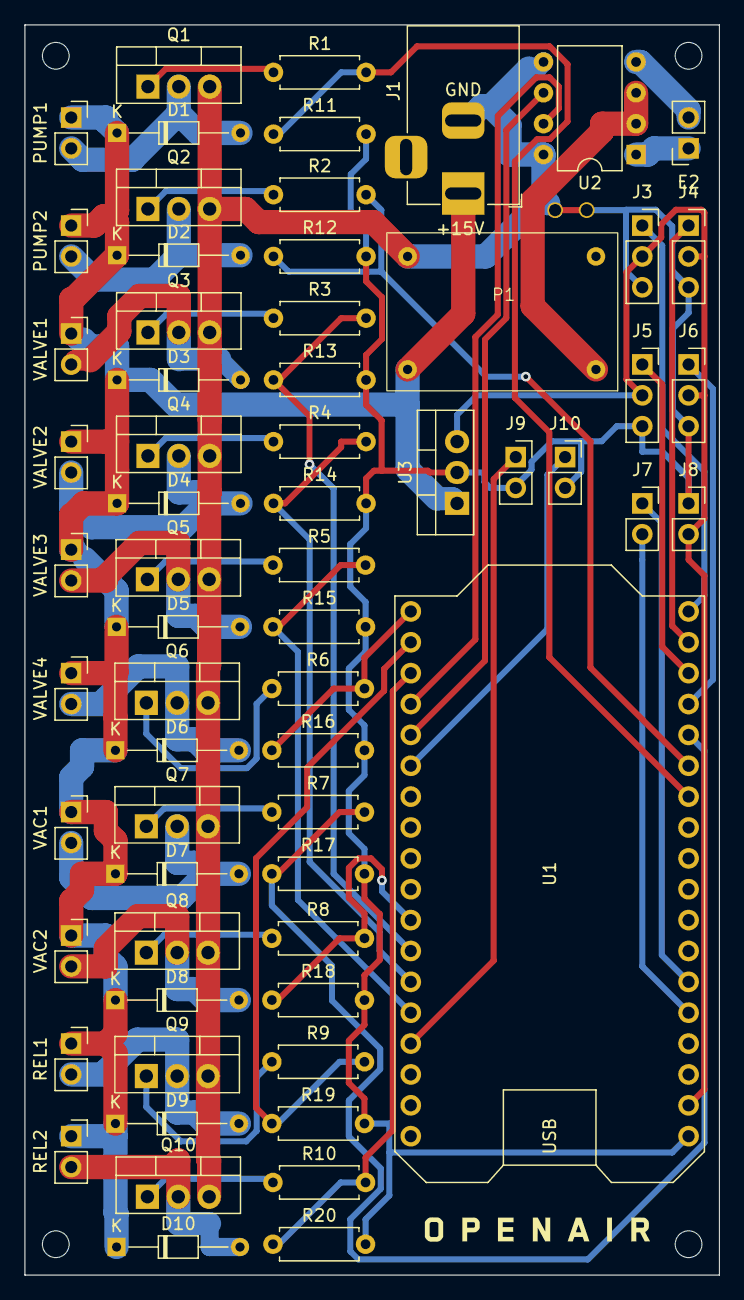
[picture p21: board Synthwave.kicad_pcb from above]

Board: 2 copper layers, 57.1 x 102.9 mm, 69 parts (0 on the bottom side), 47 nets.

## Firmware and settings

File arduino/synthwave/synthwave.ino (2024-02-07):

#define WIFI_Kit_32_V3 true

#include <WiFi.h>
#include <AsyncTCP.h>
#include <FS.h>
#include <SPIFFS.h>
#include <ESPAsyncWebServer.h>
#include <ElegantOTA.h>
#include "heltec.h"
#include <Wire.h>
#include "SparkFun_SCD30_Arduino_Library.h" // Include the SCD30 library


#define DEVICE_PUMP1 7
#define DEVICE_PUMP2 6
#define DEVICE_VAC1 5
#define DEVICE_VAC2 34
#define DEVICE_VALVE1 33
#define DEVICE_VALVE2 47
#define DEVICE_VALVE3 48
#define DEVICE_VALVE4 46
#define DEVICE_RELEASE1 45
#define DEVICE_RELEASE2 42
#define DEVICE_ELECTRODE1 40
#define DEVICE_ELECTRODE2 41

#define SENSOR_FLOAT1 39
#define SENSOR_FLOAT2 20
#define SENSOR_PH1 3
#define SENSOR_PH2 4

SCD30 airSensor;

// const char *ssid = "YOUR_SSID";
// const char *password = "YOUR_PASSWORD";
const char *ssid = "Thompson Creek Yacht Club";
const char *password = "winecountry";

// Choose whether you want to enable data logging, and if so, where you want to send the data.
// This must be an influxdb server, either hosted locally on your network or via Influx Cloud.
const bool DISABLE_LOGGING = false;
const char *influxdb_url = "http://192.168.1.42:8086/";

volatile bool startFilling = false;
String currentRoutine = "idle";
String currentStatus = "";
int co2 = 0;

AsyncWebServer server(80);

void setup(void) {
  Heltec.begin(true /*DisplayEnable Enable*/, false /*LoRa Disable*/, true /*Serial Enable*/);
  delay(100);
  Heltec.display->clear();

  // Serial.begin(115200);
  WiFi.mode(WIFI_STA);
  WiFi.begin(ssid, password);
  // Serial.println("");
  Heltec.display->setFont(ArialMT_Plain_16);

  Wire1.begin(1,2);

  delay(200);
  
  if (airSensor.begin(Wire1) == false) {
    display("No air sensor");
    delay(1000);
  }

  // Initialize output pins as OUTPUT
  digitalWrite(DEVICE_PUMP1, LOW);
  pinMode(DEVICE_PUMP1, OUTPUT);
  digitalWrite(DEVICE_PUMP2, LOW);
  pinMode(DEVICE_PUMP2, OUTPUT);
  digitalWrite(DEVICE_VAC1, LOW);
  pinMode(DEVICE_VAC1, OUTPUT);
  digitalWrite(DEVICE_VAC2, LOW);
  pinMode(DEVICE_VAC2, OUTPUT);
  digitalWrite(DEVICE_VALVE1, LOW);
  pinMode(DEVICE_VALVE1, OUTPUT);
  digitalWrite(DEVICE_VALVE2, LOW);
  pinMode(DEVICE_VALVE2, OUTPUT);
  digitalWrite(DEVICE_VALVE3, LOW);
  pinMode(DEVICE_VALVE3, OUTPUT);
  digitalWrite(DEVICE_VALVE4, LOW);
  pinMode(DEVICE_VALVE4, OUTPUT);
  digitalWrite(DEVICE_RELEASE1, LOW);
  pinMode(DEVICE_RELEASE1, OUTPUT);
  digitalWrite(DEVICE_RELEASE2, LOW);
  pinMode(DEVICE_RELEASE2, OUTPUT);

  digitalWrite(DEVICE_ELECTRODE1, LOW);
  pinMode(DEVICE_ELECTRODE1, OUTPUT);
  digitalWrite(DEVICE_ELECTRODE2, LOW);
  pinMode(DEVICE_ELECTRODE2, OUTPUT);

  // Initialize input pins
  pinMode(SENSOR_FLOAT1, INPUT); // Surprise! Pin 39 needs a hardware pullup.
  pinMode(SENSOR_FLOAT2, INPUT_PULLUP); 
 
  // Wait for connection
  while (WiFi.status() != WL_CONNECTED) {
    delay(500);
    Serial.print(".");
    Heltec.display->drawString(0, 10, "Connecting...");
    Heltec.display->display();
  }

  delay(2000);

  /*
  Serial.println("");
  Serial.print("Connected to ");
  Serial.println(ssid);
  Serial.print("IP address: ");
  Serial.println(WiFi.localIP());
  */

  Heltec.display->clear();
  Heltec.display->drawString(0, 10, WiFi.localIP().toString());
  Heltec.display->display();

  if (!SPIFFS.begin(true)) {
    Serial.println("An error has occurred while mounting SPIFFS");
    return;
  } else {
    Serial.println(" Total Bytes: " + String(SPIFFS.totalBytes()));
    Serial.println(" Used Bytes: " + String(SPIFFS.usedBytes()));
  }

  File root = SPIFFS.open("/");
  File file = root.openNextFile();
  
  
  while(file){
    Serial.println(file.name());
    file = root.openNextFile();
    delay(1000);
  }

  server.serveStatic("/", SPIFFS, "/").setDefaultFile("index.html");

  // Status endpoint
  server.on("/api/status", HTTP_GET, [](AsyncWebServerRequest *request) {
    getStatus(request);
  });

  // Individual device endpoints.  These probably shouldn't be available to the network,
  // although they can be useful for debugging.
  server.on("/api/device/vac1", HTTP_POST, [](AsyncWebServerRequest *request) {
    toggleDevice("VAC1", request);
  });
  server.on("/api/device/vac2", HTTP_POST, [](AsyncWebServerRequest *request) {
    toggleDevice("VAC2", request);
  });
  server.on("/api/device/pump1", HTTP_POST, [](AsyncWebServerRequest *request) {
    toggleDevice("PUMP1", request);
  });
  server.on("/api/device/pump2", HTTP_POST, [](AsyncWebServerRequest *request) {
    toggleDevice("PUMP2", request);
  });
  server.on("/api/device/valve1", HTTP_POST, [](AsyncWebServerRequest *request) {
    toggleDevice("VALVE1", request);
  });
  server.on("/api/device/valve2", HTTP_POST, [](AsyncWebServerRequest *request) {
    toggleDevice("VALVE2", request);
  });
  server.on("/api/device/valve3", HTTP_POST, [](AsyncWebServerRequest *request) {
    toggleDevice("VALVE3", request);
  });
  server.on("/api/device/valve4", HTTP_POST, [](AsyncWebServerRequest *request) {
    toggleDevice("VALVE4", request);
  });
  server.on("/api/device/release1", HTTP_POST, [](AsyncWebServerRequest *request) {
    toggleDevice("RELEASE1", request);
  });
  server.on("/api/device/release2", HTTP_POST, [](AsyncWebServerRequest *request) {
    toggleDevice("RELEASE2", request);
  });
  server.on("/api/device/electrode1", HTTP_POST, [](AsyncWebServerRequest *request) {
    toggleDevice("ELECTRODE1", request);
  });
  server.on("/api/device/electrode2", HTTP_POST, [](AsyncWebServerRequest *request) {
    toggleDevice("ELECTRODE2", request);
  });

  // Routines
  server.on("/api/routine/fill1", HTTP_POST, [](AsyncWebServerRequest *request) {
    currentRoutine = "FILL1";
    getStatus(request);
  });

  server.on("/api/routine/fill2", HTTP_POST, [](AsyncWebServerRequest *request) {
    currentRoutine = "FILL2";
    getStatus(request);
  });

  server.on("/api/routine/transfer1to2", HTTP_POST, [](AsyncWebServerRequest *request) {
    currentRoutine = "TRANSFER1TO2";
    getStatus(request);
  });

  server.on("/api/routine/transfer2to1", HTTP_POST, [](AsyncWebServerRequest *request) {
    currentRoutine = "TRANSFER2TO1";
    getStatus(request);
  });

  server.on("/api/routine/stop", HTTP_POST, [](AsyncWebServerRequest *request) {
    currentRoutine = "idle";
    everythingOff();
    getStatus(request);
  });

  server.on("/api/routine/electrodes_forward", HTTP_POST, [](AsyncWebServerRequest *request) {
    currentRoutine = "ELECTRODES_FORWARDS";
    getStatus(request);
  });

  server.on("/api/routine/electrodes_backward", HTTP_POST, [](AsyncWebServerRequest *request) {
    currentRoutine = "ELECTRODES_BACKWARDS";
    getStatus(request);
  });

  server.onNotFound([](AsyncWebServerRequest *request) {
    if (request->method() == HTTP_OPTIONS) {
      request->send(200);
    } else {
      request->send(404);
    }
  });

  ElegantOTA.begin(&server);    // Start ElegantOTA

  DefaultHeaders::Instance().addHeader("Access-Control-Allow-Headers", "Accept, Content-Type, Authorization");
  DefaultHeaders::Instance().addHeader("Access-Control-Allow-Credentials", "true");
  DefaultHeaders::Instance().addHeader("Access-Control-Allow-Origin", "*");

  server.begin();
  // Serial.println("HTTP server started");
}

void everythingOff() {
  digitalWrite(DEVICE_PUMP1, LOW);
  digitalWrite(DEVICE_PUMP2, LOW);
  digitalWrite(DEVICE_VAC1, LOW);
  digitalWrite(DEVICE_VAC2, LOW);
  digitalWrite(DEVICE_VALVE1, LOW);
  digitalWrite(DEVICE_VALVE2, LOW);
  digitalWrite(DEVICE_VALVE3, LOW);
  digitalWrite(DEVICE_VALVE4, LOW);
  digitalWrite(DEVICE_RELEASE1, LOW);
  digitalWrite(DEVICE_RELEASE2, LOW);
  digitalWrite(DEVICE_ELECTRODE1, LOW);
  digitalWrite(DEVICE_ELECTRODE2, LOW);
}

void toggleDevice(const String &deviceName, AsyncWebServerRequest *request) {
  int devicePin = getDevicePin(deviceName);
  String output = deviceName;

  if (devicePin == -1) {
    request->send(400, "text/plain", "Invalid device name: " + deviceName);
    return;
  }

  // Read pin high/low status
  int currentState = digitalRead(devicePin);

  // Toggle the state
  if (currentState == LOW) {
    digitalWrite(devicePin, HIGH);
    output = output + " " + "on";
  } else {
    digitalWrite(devicePin, LOW);
    output = output + " " + "off";
  }

  display(output);
  getStatus(request);
}

void display(String message){
  Heltec.display->clear();
  Heltec.display->drawString(0, 10, message);
  Heltec.display->display();
}

void getStatus(AsyncWebServerRequest *request) {

  //AsyncResponseStream *response = request->beginResponseStream("application/json");
  //response->addHeader("Access-Control-Allow-Origin", "*");
  //response->addHeader("Access-Control-Allow-Methods", "GET, POST, PUT, DELETE");
  //response->print(results);
  currentStatus = buildStatusString();
  request->send(200, "text/plain", currentStatus);
}

int getDevicePin(const String &deviceName) {
  if (deviceName == "PUMP1") return DEVICE_PUMP1;
  if (deviceName == "PUMP2") return DEVICE_PUMP2;
  if (deviceName == "VAC1") return DEVICE_VAC1;
  if (deviceName == "VAC2") return DEVICE_VAC2;
  if (deviceName == "VALVE1") return DEVICE_VALVE1;
  if (deviceName == "VALVE2") return DEVICE_VALVE2;
  if (deviceName == "VALVE3") return DEVICE_VALVE3;
  if (deviceName == "VALVE4") return DEVICE_VALVE4;
  if (deviceName == "RELEASE1") return DEVICE_RELEASE1;
  if (deviceName == "RELEASE2") return DEVICE_RELEASE2;
  if (deviceName == "ELECTRODE1") return DEVICE_ELECTRODE1;
  if (deviceName == "ELECTRODE2") return DEVICE_ELECTRODE2;

  return -1;  // Invalid device name
}

// TODO: decide if this is dumb
String buildStatusString() {
  String status = "[";
  status += "\"" + currentRoutine + "\""",";
  status += String(millis()) + ",";
  status += String(digitalRead(DEVICE_PUMP1)) + ",";
  status += String(digitalRead(DEVICE_PUMP2)) + ",";
  status += String(digitalRead(DEVICE_VAC1)) + ",";
  status += String(digitalRead(DEVICE_VAC2)) + ",";
  status += String(digitalRead(DEVICE_VALVE1)) + ",";
  status += String(digitalRead(DEVICE_VALVE2)) + ",";
  status += String(digitalRead(DEVICE_VALVE3)) + ",";
  status += String(digitalRead(DEVICE_VALVE4)) + ",";
  status += String(digitalRead(DEVICE_RELEASE1)) + ",";
  status += String(digitalRead(DEVICE_RELEASE2)) + ",";
  status += String(digitalRead(DEVICE_ELECTRODE1)) + ",";
  status += String(digitalRead(DEVICE_ELECTRODE2)) + ",";
  status += String(digitalRead(SENSOR_FLOAT1)) + ",";
  status += String(digitalRead(SENSOR_FLOAT2)) + ",";
  status += String(analogRead(SENSOR_PH1)) + ",";
  status += String(analogRead(SENSOR_PH2)) + ",";
  status += String(co2);
  status += "]";

  return status;
}

void loop(void) {
  if (currentRoutine == "FILL1") {
    if (digitalRead(SENSOR_FLOAT1) == HIGH){
      // Continue filling a bit past the sensor level
       delay(500);
       currentRoutine = "idle";
       everythingOff();
       display("Filled!");
    } else if (digitalRead(DEVICE_VALVE3) == HIGH) {
      // Ensure VALVE3 is open before running pump
      digitalWrite(DEVICE_PUMP1, HIGH);
    } else {
      digitalWrite(DEVICE_VALVE3, HIGH);
    }
  }

  if (currentRoutine == "FILL2") {
    if (digitalRead(SENSOR_FLOAT2) == HIGH){
       // Continue filling a bit past the sensor level
       delay(500);
       currentRoutine = "idle";
       everythingOff();
       display("Filled!");
    } else if (digitalRead(DEVICE_VALVE1) == HIGH) {
      // Ensure VALVE1 is open before running pump
      digitalWrite(DEVICE_PUMP2, HIGH);
    } else {
      digitalWrite(DEVICE_VALVE1, HIGH);
    }
  }

    if (currentRoutine == "TRANSFER1TO2") {
      // Float sensor should be active in order to begin transfer routine, but we won't enforce that for now.
      if (digitalRead(SENSOR_FLOAT2) == HIGH){
       currentRoutine = "idle";
       everythingOff();
       display("Transferred!");
    } else if (digitalRead(DEVICE_VALVE1) == HIGH && digitalRead(DEVICE_VALVE4) == HIGH) {
      // Ensure VALVE1 and VALVE4 are open before running pump
      digitalWrite(DEVICE_PUMP2, HIGH);
    } else {
      digitalWrite(DEVICE_VALVE1, HIGH);
      delay(100);
      digitalWrite(DEVICE_VALVE4, HIGH);
    }
  }

  if (currentRoutine == "TRANSFER2TO1") {
      // Float sensor should be active in order to begin transfer routine, but we won't enforce that for now.
      if (digitalRead(SENSOR_FLOAT1) == HIGH){
       currentRoutine = "idle";
       everythingOff();
       display("Transferred!");
    } else if (digitalRead(DEVICE_VALVE2) == HIGH && digitalRead(DEVICE_VALVE3) == HIGH) {
      // Ensure VALVE2 and VALVE3 are open before running pump
      digitalWrite(DEVICE_PUMP1, HIGH);
    } else {
      digitalWrite(DEVICE_VALVE2, HIGH);
      delay(100);
      digitalWrite(DEVICE_VALVE3, HIGH);
    }
  }

  if (airSensor.dataAvailable()) {
    co2 = airSensor.getCO2();
  }
  
  delay(20);
  currentStatus = buildStatusString();
  delay(1000);
}

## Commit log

2023-09-01 Add 3d printing files
    [omega.scad, synthwave.scad, synthwave_back.stl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]
2023-09-07 Rename and move files
    [omega.scad, synthwave.scad, synthwave_back.stl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]
2023-10-26 Minor updates
    [synthwave.scad]
2023-11-11 Fit improvements
    [synthwave.scad, synthwave_solenoid_fitting.stl, test_fit.stl]
2023-11-15 Add makefile, improve design
    [breadboard_cover.stl, container_cover.stl, pump_bracket.stl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]
2023-11-15 Improve sleekness
    [breadboard_cover.stl, container_cover.stl, pump_bracket.stl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]
2023-11-18 Move holes forward for easier tube routing
    [container_cover.stl, pump_bracket.stl, synthwave.scad]
2023-11-30 Add standoffs for PCB
    [standoffs.stl]
2023-11-30 Add pcb prototype design
    [Synthwave v2-B_Cu.gbr, Synthwave v2-B_Mask.gbr, Synthwave v2-B_Paste.gbr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]
2023-11-30 Update scad file
    [synthwave.scad]
2023-11-30 remove unneeded file
    [omega.scad]
2023-11-30 Rename files
    [Synthwave-B_Cu.gbr, Synthwave-B_Mask.gbr, Synthwave-B_Paste.gbr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]
2023-12-03 Many small updates
    [Synthwave.kicad_pcb, Synthwave.kicad_sch, synthwave.scad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]
2023-12-03 Small edition
    [Synthwave_Smaller_Edition.kicad_pcb]
2023-12-03 Update and upgrades
    [Synthwave.kicad_pcb, Synthwave.kicad_sch, Synthwave_Smaller_Edition.kicad_pcb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]
2023-12-15 Add model updates and various files
    [Synthwave.kicad_pcb, container_cover.stl, pump_bracket.stl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]
2023-12-16 Add List of Materials
2023-12-16 Update MATERIALS
2023-12-17 Update link to materials
2023-12-17 Update ardiuno code + binaries
    [synthwave.scad]
2023-12-23 Work on back cover
    [synthwave.scad]
2023-12-23 Various updates
    [container_cover.stl, electrode_holder.stl, pump_bracket.stl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]
2023-12-23 Update makefile and remove top shelf
    [container_cover.stl, electrode_holder.stl, pump_bracket.stl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]
2023-12-23 Update software for routines
    [pump_bracket.stl, top_shelf.stl]
2024-01-18 Remove unnneeded files
    [Synthwave-B_Cu.gbr, Synthwave-B_Mask.gbr, Synthwave-B_Paste.gbr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]
2024-01-22 Add TODO for pcb
2024-01-28 Further work on routines. Reading of pH sensor ADC pins.
2024-01-29 Updates to arduino files. Add ink spreader model
    [ink_spreader.stl]
2024-01-29 Add electrodes guide
2024-02-01 Update electrode information, many small tweaks
    [Synthwave.kicad_pcb, ink_spreader.scad, ink_spreader.stl]
2024-02-07 Last minute modifications to v1
    [synthwave.scad]
